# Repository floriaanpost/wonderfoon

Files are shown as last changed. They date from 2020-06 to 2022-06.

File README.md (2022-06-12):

<meta name="google-site-verification" content="D2DzTi8eTN-HyuHSnyPzxfvAiq60_1QDBox8yPDGH7g" />

# V3 is klaar!
Omdat ik zelf ook weer plezier kreeg in het project heb ik v3 gemaakt. Helaas (nog) geen DTMF, maar wel betere stabiliteit (minder vaak/nooit fouten met pulsen tellen) en makkelijker om de firmware te updaten (ISCP port). Ook zit er een LED op het board voor debugging (of om te laten zien dat hij aan staat).

Ik hoop dat het met deze versie gemakkelijker en leuker wordt voor mensen om te experimenteren met de code en het precies zo te maken als je zelf wil.

Heb je nog een oude versie, dan kun je wel de firmware gebruiken van v3 (alleen in wonderfoon.ino moet je OLD_PIN_CONFIG uncommenten), of anders kun je alles van v2 nog terugvinden in de v2 branch.

Verder valt het mij op dat mensen het lastig vinden om de Attiny te programmeren. Mocht dit je tegenhouden dan kan ik eventueel ook voorgeprogrammeerde chips opsturen, en vaak heb ik ook nog wel andere onderdelen liggen, en als je heel graag een wonderfoon wil, maar je kunt niet solderen, dan wil ik er misschien zelfs wel een voor je in elkaar solderen. Vraag even naar de mogelijkheden op de mail :)

# Wonderfoon mini
De Wonderfoon is een ouderwetse draaischijftelefoon waar je muziek te horen krijgt door de hoorn als je een nummer draait. Het is oorspronkelijk bedacht als "speelgoed" voor (demente) ouderen door Leo Willems. De ouderwetse telefoon uit hun jonge jaren, gecombineerd met muziek uit dezelfde tijd is vaak en leuke ervaring voor ouderen. Het oorspronkelijke idee is gemaakt met een Raspberry Pi (een soort kleine computer). Voor het oorspronkelijke plan moet de telefoon (onherstelbaar) gesloopt worden. Met inspiratie van [een project van Jan Derogee (TeleJukebox)](https://github.com/JanDerogee/TeleJukebox) heb ik een nieuw type Wonderfoon ontworpen. Hierbij hoeft de telefoon niet gesloopt te worden en kun je de stekker van de telefoon gemakkelijk in een doosje stoppen dat zich gedraagt als de telefooncentrale. Ook is de Raspberry Pi vervangen door een kleine mp3 speler (DFPlayer Mini) en een microcontroller (ATTiny85).

Ik krijg vaak soortgelijke vragen door mensen die de wonderfoon aan het bouwen zijn, onderaan deze pagina staat een FAQ sectie, lees die graag eerst voor je een vraag aan mij stuurt. Die beantwoord ik graag, maar ik houd ook erg van mijn weekend :)

# Foto's
De complete wonderfoon is in een klein doosje gestopt wat een standaard doosje is dat gemaakt wordt door Kopp en Q-link. Het printpaatje is zo ontworpen dat het precies past.

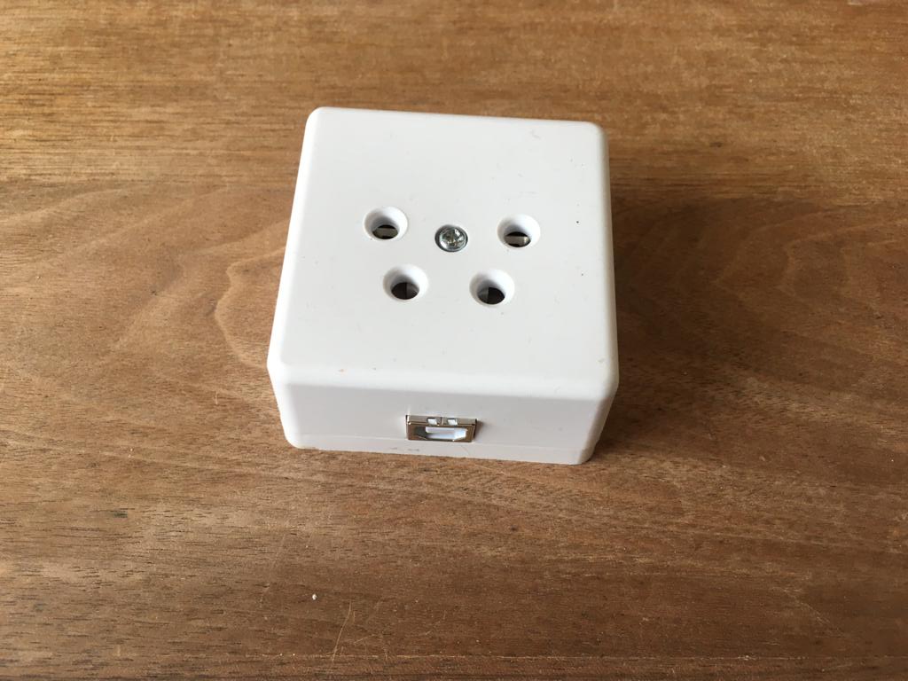
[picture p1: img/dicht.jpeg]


Als je het doosje openschroeft zie je het volgende:

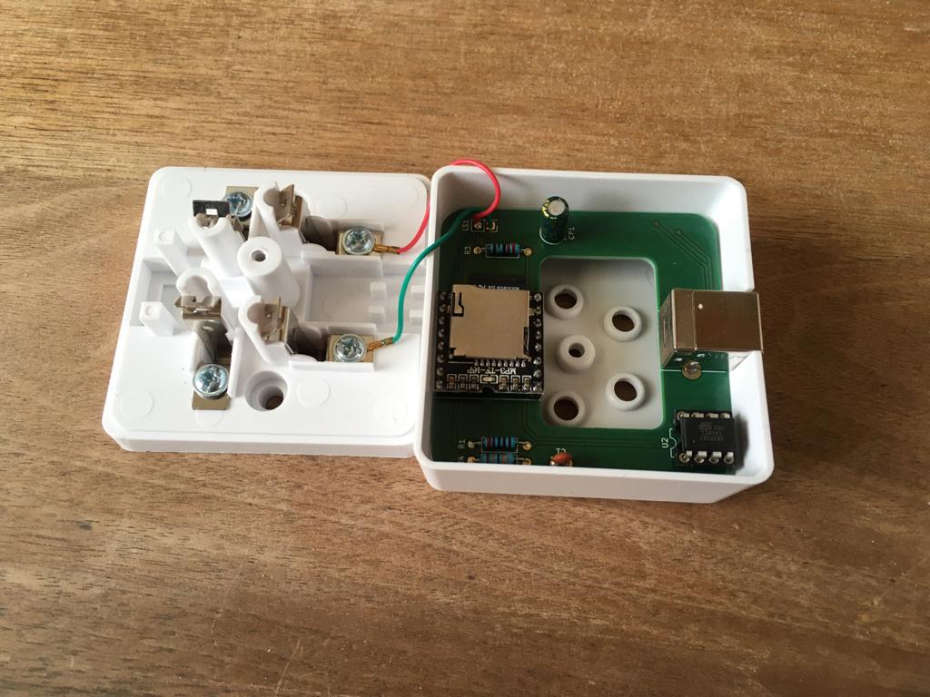
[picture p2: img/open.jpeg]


Er is een speciaal printplaatje ontworpen die precies in het doosje past.

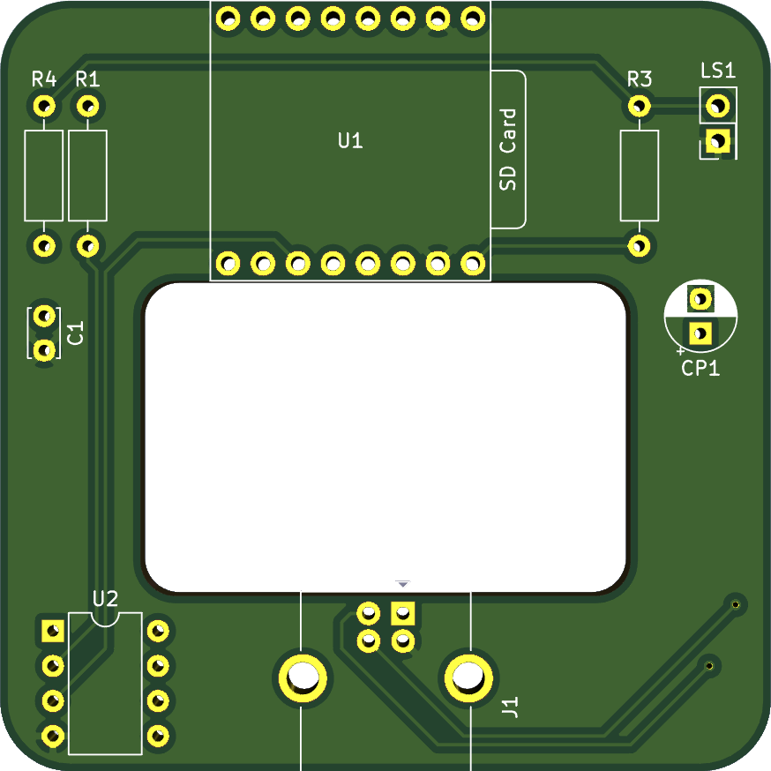
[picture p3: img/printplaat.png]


# Ik wil er een bouwen
In het bestand Bouwhandleiding Wonderfoon staat een handleiding van hoe je er een kunt solderen en programmeren. Met de gerberfiles kun je een printplaat bestellen. Let er goed op bij het bestellen dat je controleert of het midden ook echt een gat wordt voor je de bestelling plaatst. Ik heb ook nog behoorlijk wat printplaatjes liggen, dus je kunt ze ook bij mij bestellen.

# Componentenlijst
Ik kreeg de vraag waar je de componenten kunt kopen. Hieronder een voorbeeld. Dit is zonder enige twijfel niet de goedkoopste optie, maar het kan je in ieder geval helpen met de juiste componenten vinden:

- Attiny85: https://opencircuit.nl/Product/ATtiny85-DIP8
- DFPlayer mini: https://opencircuit.nl/Product/DFPlayer-Een-mini-mp3-speler-voor-Arduino
- Header pins (ICSP): https://opencircuit.nl/Product/Male-header-2x40-2.54mm-zwart
- USB type B connector: https://www.conrad.nl/p/econ-connect-usbbu1bn-usb-connector-bus-inbouw-horizontaal-wit-1-stuks-1883654
- 10 uF elco: https://opencircuit.nl/Product/10uF-35V-Condensator-elektrolytisch
- 1 uF elco: https://opencircuit.nl/Product/1uF-450V-Condensator-elektrolytisch
- LED (optioneel): https://opencircuit.nl/Product/Rood-5mm-diffuse-LED-10-stuks
- 10 kOhm weerstand: https://opencircuit.nl/Product/10K%CE%A9-Metaalfilm-weerstand-1-4W-10-stuks
- 220 Ohm weerstand: https://opencircuit.nl/Product/220%CE%A9-Metaalfilm-weerstand-1-4W-10-stuks
- 2.7 kOhm (dit is 2kOhm, maar dat is ook wel prima): https://opencircuit.nl/Product/2K%CE%A9-Metaalfilm-weerstand-1-4W-10-stuks
- Telefooncontactdoos https://www.gamma.nl/assortiment/q-link-telefoon-contactdoos-opbouw-modulair-4-polig-wit/p/B547149

# De liedjes nummeren is veel moeite...
Hier heeft Daan een python scriptje voor gemaakt dat je kunt gebruiken:
https://github.com/daanv98/mp3nu

Je kunt ook file renamer gebruiken:
http://www.sherrodcomputers.com/products_filerenamer.cfm

# FAQ
Ik krijg vaak soortgelijke vragen die ik hieronder zal beantwoorden:

#### Hoe moet ik de bestanden op de SD kaart zetten (lees dit sowieso even door, dit zorgt voor het meest problemen)
De DFplayer mini is een handig en goedkoop stukje hardware, maar heeft een paar vreemde eigenschappen, waar je rekening mee moet houden als je bestanden op de SD kaart zet. Met de onderstaande stappen gaat het (bij mij althans) altijd goed:

- Formatteer de SD kaart (FAT)
- Zet eerst de 01/ map erop (https://github.com/floriaanpost/wonderfoon/tree/master/muziek). Dit mapje bevat de kiestoon die je hoort als je de hoorn van de haak neemt en de verbinding verbroken toon en nog wat zaken. Het is van cruciaal belang dat je dit eerst doet voor dat je iets met een MP3 map doet. Dit komt omdat de DFPlayer mini de nummering doet op basis van de volgorde waarop de liedjes op de SD kaart zijn gezet, dus die moeten als aller eerst op de SD kaart worden gezet.
- Maak hierna een mapje genaamd MP3 in de hoofdmap. Zet hierin liedjes op volgorde genummerd, startend met precies 4 cijfers. Alleen de eerste vier cijfers maken uit, daarna kun je alles schrijven wat je wil. Dit nummeren is veel werk, dus daarvoor kun je eventueel het Python scriptje van Daan gebruiken (zie hierboven), of zelf een bash-kunstwerktje maken, of gewoon handmatig te werk gaan. Let op dat er geen gaten zitten in de nummering! Zie als voorbeeld: https://github.com/floriaanpost/wonderfoon/tree/master/muziek/MP3
- Laat hierna de 01 map voor altijd met rust, je kunt wel dingen aanpassen in de MP3 map, maar let op dat er geen verborgen bestanden ontstaan op de SD kaart, die ziet de DFPlayer mini niet als verborgen bestanden, en dat kan zorgen voor vreemde problemen.

Als je een mac hebt (ik ben zelf zo'n persoon) heb je een beetje een probleem. Mac is heel gretig in het produceren van verborgen bestanden en hele trash mappen op sd kaarten. Het is mij maar zelden gelukt om het daar goed te doen. Ik pak nu altijd mijn Linux laptop, wat verreweg het beste gaat op dit gebied. Windows zorgt ook voor weinig problemen.

#### Ik heb de bestanden precies zoals hierboven op mijn SD kaart gezet, en toch werkt het niet.
Ik heb iemand gehad die SD kaartjes had gekocht die ook ik niet aan de praat heb gekregen. We hebben nog steeds geen idee wat het probleem was. Ik heb vaak de allergoedkoopste Kingston SD kaart gebruikt die ik kon vinden en daar nog nooit problemen mee gehad. Geen idee dus wat dit precies kan zijn, maar een andere SD kaart proberen is geen slecht idee.

#### Ik denk dat mijn ATtiny85 niet goed is geprogrammeerd
Als de led op enig moment knippert, betekent dat hoogstwaarschijnlijk dat de ATtiny85 goed is geprogrammeerd, aangezien die de LED aanstuurt, als de LED dus knippert, zoek dan naar een andere oorzaak dan de ATtiny85. Doet de LED helemaal niets, dan is er een goede kans dat de ATtiny85 inderdaad niet goed is geprogrammeerd. 

#### De LED blijft knipperen, en de wonderfoon werkt niet
Zo lang de led knippert is de ATtiny85 bezig met verbinding maken met de kleine MP3 speler, de DFPLayer mini. Dit gaat zelden meteen goed zodra je hem in het stopcontact steekt, de DFPlayer heeft wat meer tijd nodig om op te starten dan de ATtiny85. Als het knipperen echter niet stopt, dan gaat er iets mis. Dit kan betekenen dat er geen SD kaart in de DFPlayer zit (maar ik ga ervan uit dat jullie dat niet vergeten), of dat er iets is waardoor de bestanden op de SD kaart niet goed gelezen kunnen worden, zie het eerste punt over hoe je bestanden op de SD kaart moet zetten, en het tweede punt over sommige SD kaarten die niet werken.

#### Ik hoor bijvoorbeeld de "verkeerd verbonden" toon als ik de hoorn opneem in plaats van de kiestoon, of meteen een liedje
Zet de liedjes juist op de SD kaart, zoals beschreven in het eerste punt. Als je een mac hebt, probeer een windows/linux computer te vinden en probeer het daarmee, of zoek uit hoe het wel lukt op een mac en vertel het mij ;)

#### Ik wil de ATtiny85 programmeren met een Arduino, maar het lukt me niet
Een USBasp is veel makkelijker om te programmeren, en heel goedkoop, maar als je het toch met een arduino wil doen kun je deze handleiding volgen:
https://create.arduino.cc/projecthub/arjun/programming-attiny85-with-arduino-uno-afb829
Er is alleen een ding dat hier niet vermeld staat en dat is dat wanneer je de "ArduinoISP" sketch op de arduino zet je regel 81 moet uncommenten (// #define USE_OLD_STYLE_WIRING). Verder is gebruik ik een kloksnelheid van 1MHz voor de attiny (hoewel hoger ook zou moeten werken).

#### De sketch compileert niet bij het programmeren. 
Je moet de attiny eerst toevoegen aan de arduino IDE.
Volg de instructies van deze repository: https://github.com/damellis/attiny

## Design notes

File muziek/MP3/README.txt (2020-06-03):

Als voorbeeld staan er twee "nummers" in deze map. In het echt moeten dat natuurlijk mp3 bestanden zijn. Wel moeten ze op precies deze manier genummerd worden. Vier getallen vanaf 0001, daarna een spatie en dan mag er alles staan wat je zelf maar wil. Ook mogen er geen getallen worden overgeslagen want dan wordt de lijn verbroken als je wel dat nummer probeert te bellen.

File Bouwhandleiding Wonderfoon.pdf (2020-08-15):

## Handleiding Wonderfoon

Floriaan Post

February 2020

## Inleiding

De Wonderfoon is een ouderwetse draaischijftelefoon waar je muziek te horen krijgt door de hoorn als je een nummer draait. Het is oorspronkelijk bedacht als "speelgoed" voor (demente) ouderen door Leo Willems. De ouderwetse telefoon uit hun jonge jaren, gecombineerd met muziek uit dezelfde tijd is vaak en leuke ervaring voor ouderen. Het oorspronkelijke idee is gemaakt met een Raspberry Pi (een soort kleine computer). Voor het oorspronkelijke plan moet de telefoon (onherstelbaar) gesloopt worden. Met inspiratie van een project van Jan Derogee (https://github.com/JanDerogee/TeleJukebox) heb ik een nieuw type Wonderfoon ontworpen. Hierbij hoeft de telefoon niet gesloopt te worden en kun je de stekker van de telefoon gemakkelijk in een doosje stoppen dat zich gedraagt als de telefooncentrale. Ook is de Raspberry Pi vervangen door een kleine mp3 speler (DFPlayer Mini) en een microcontroller (ATTiny85). De onderstaande bouwhandleiding is bedoelt voor die versie van de Wonderfoon.

## Componenten

De volgende electronische componenten zijn nodig voor het maken van de wonderfoon:

Code op printplaat | Component | Uitleg
U1 | DFPlayer mini | Mini mp3 speler
U2 | ATTiny85 | Microcontroller
J1 | USB Type B socket
J2 | ICSP port | 2 x 3 header pins
CP1 | 10 uF | Elektrolytische condensator
CP2 | 1 uF | Elektrolytische condensator
R1 | 2.7 kΩ | Weerstand
R2 | 220 Ω | Weerstand
R3 | 10 kΩ | Weerstand
R4 | 220 Ω | Weerstand (Optioneel)
D1 | LED | Optionele LED voor debugging
SD Card | | Micro SD kaart

De printplaat waarop de componenten gesoldeerd moeten worden inclusief nummering staat in figuur 1a.

Het laatste component dat uitleg verdient is het doosje waar het geheel in moet. Dit is een doosje dat eigenlijk is bedoelt om van een ouderwetse PPT stekker (de stekker die aan de draaischijftelefoon zit) naar je modem te kunnen gaan. Dit doosje is erg geschikt voor de Wonderfoon. Er zijn twee opties hiervoor, namelijk de versie van Q-Link (verkrijgbaar bij onder andere de Gamma) en die van Kopp (verkrijgbaar bij onder andere de Praxis). Deze zijn min of meer identiek en beiden te gebruiken, maar ik heb zelf een voorkeur voor de versie van Q-Link want die is iets mooier afgewerkt. De kosten zijn (min of meer) hetzelfde. In figuur 1b staat een voorbeeld van zo’n telefooncontactdoos.

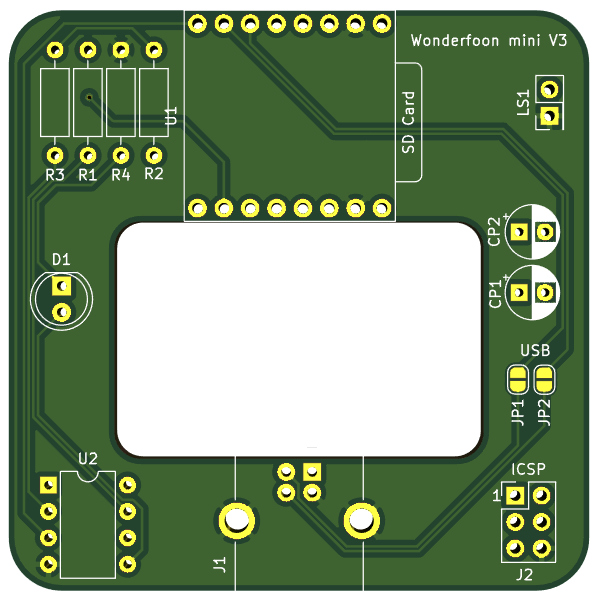
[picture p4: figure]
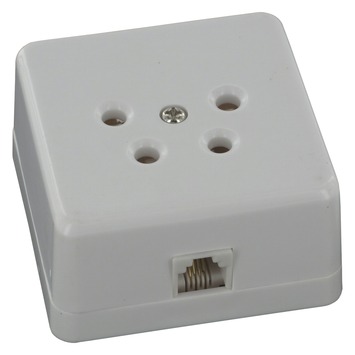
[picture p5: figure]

(a) De printplaat met de nummering van de componenten. | (b) Q-Link telefooncontactdoos

Figure 1: Speciale onderdelen

## Montage

Zorg dat de soldeerbout warm is. Bij het solderen is het belangrijk dat je beide delen die je vast wil solderen verwarmt waarna je een beetje soldeertin toevoegt en alles aan elkaar smelt. Als het er goed uitziet kun je de soldeerbout weer weghalen. Hieronder een aantal algemene tips om het solderen wat makkelijker te maken:

1. Begin met de kleinste componenten met korte pootjes. Deze vallen er weer uit als je dit pas later doet, wat het moeilijk maakt ze te monteren.
2. Je hebt maar een klein beetje soldeertin nodig per pootje dat je vastmaakt. Teveel soldeertin maakt de verbinding minder sterk en je verhoogt het risico dat er een elektrische verbinding ontstaat met een ander pootje.
3. Componenten met lange pootjes zoals weerstanden en condensatoren kun je ombuigen nadat je ze door de juiste gaatjes hebt gehaald. Hierdoor blijven ze hangen en kun je makkelijker solderen.

Gezien regel 1 kun je in dit geval het beste beginnen met het IC-voetje. Hierna maakt het allemaal wat minder uit maar ik zou adviseren om daarna de DFPlayer mini te doen. Hierna de weerstanden en de condensator. Als laatste de Elco’s (elektrolytische condensatoren) en de USB port.

Als laatste moet je de connectoren voor de telefoonlijn vast solderen. Hiervoor moet je het doosje van figuur 1b openschroeven. Je treft dan iets soortgelijks aan als in figuur 2a. Je moet alle contactpunten losschroeven en dan kan je het het geheel (het doet mij altijd denken aan een soort octopus) eruit halen. Je moet nu twee van de stroomdraden afknippen omdat je die nog nodig hebt. Ik kies altijd de rode en de groene, zie figuur 2b omdat je als het klaar is de draden ook weer aan die contactpunten vastmaakt. De rest van de "octopus" heb je niet nodig en kun je weggooien. Strip de uiteinden van de kabeltjes en soldeer ze vast bij LS1. In welk gaatje van LS1 je welke kleur draad vastmaakt maakt niet uit. Dit komt doordat de telefoon analoog is en het dus niet uitmaakt hoe om de spanning wordt aangesloten. Wat wel uitmaakt is waar je de draden vastzet in het doosje. De draden moeten naar de brede kant van de PPT stekker, zie hiervoor figuur 3.

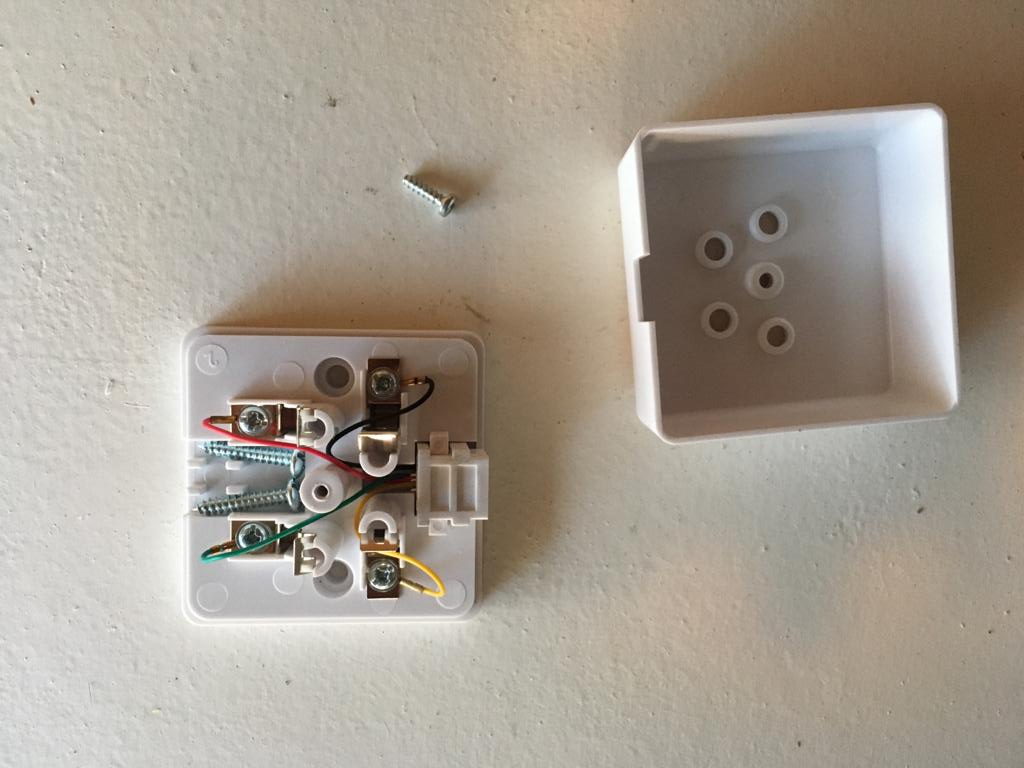
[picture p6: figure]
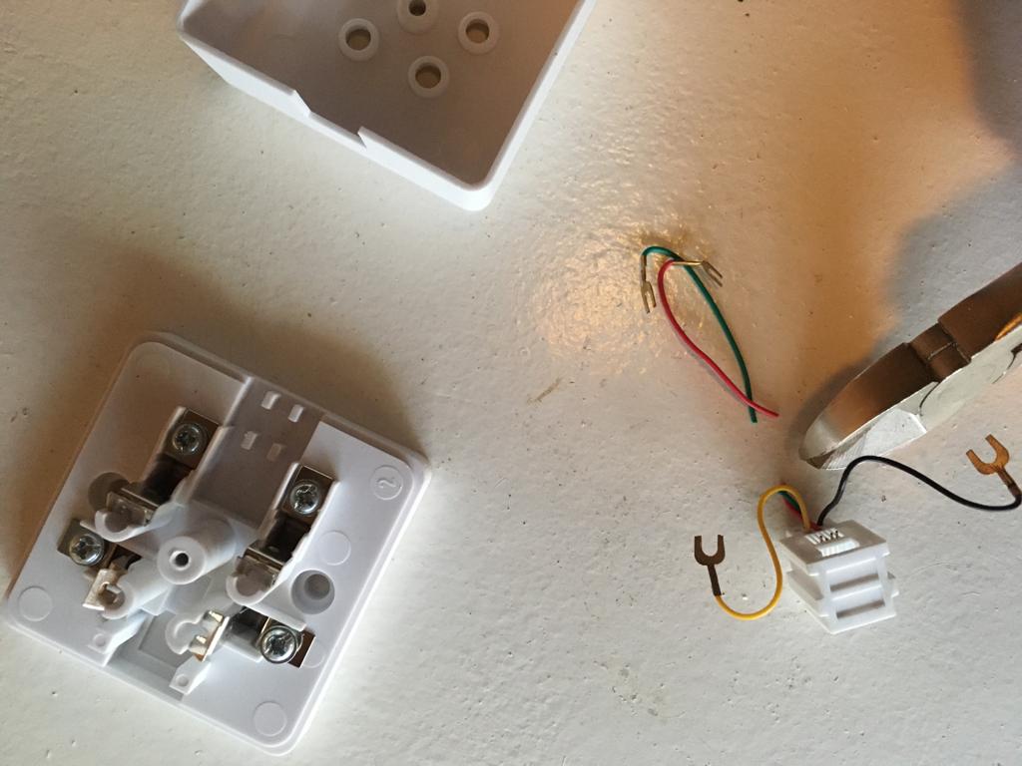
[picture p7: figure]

(a) De geopende telefooncontactdoos. | (b) Losknippen van de rode en groene draad.

Figure 2: Telefooncontactdoos demonteren


Figure 3: bevestigen draden aan het doosje.

## Microcontroller programmeren

Als alles in elkaar is gesoldeerd, is het tijd om de microcontroller (Attiny85) te programmeren. Er komt dan een klein programma op de microcontroller dat kan detecteren of de telefoon van de haak wordt gehaald en welk nummer er gedraaid wordt. Ook stuurt de microcontroller de mp3 speler aan als er gedetecteerd is welk nummer er gespeeld moet worden. Het programma is geschreven in Arduino C++. Je hebt dus het programma Arduino nodig. Dit programma is gratis te downloaden voor Windows, Mac en Linux op hun website. (https://www.arduino.cc/en/Main/Software)

ATTiny85 toevoegen in de Arduino IDE

Als je dit eenmaal hebt geinstalleerd moet je de ATTiny85 toevoegen in de Arduino IDE (je kunt niet standaard de ATTiny85 programmaren). Hieronder de korte handleiding om hem toe te voegen. Dit hoef je maar een keer te doen en kun je dus overslaan als je dit al eens gedaan hebt.

1. Klik op File → Preferences.
2. Voeg bij "Additional boards manager" de volgende url toe:

https://raw.githubusercontent.com/damellis/attiny/ide-1.6.x-boards-manager/package_damellis_attiny_index.json

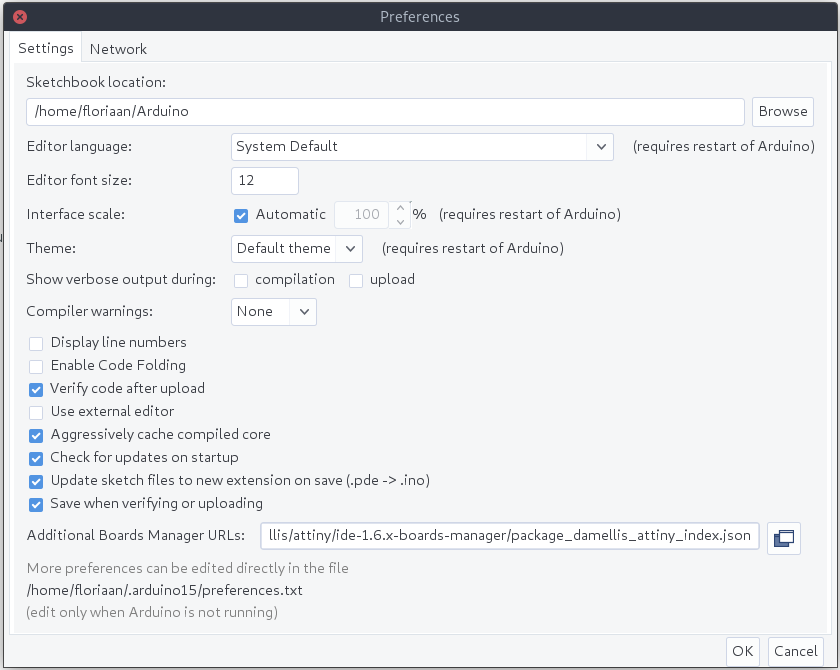
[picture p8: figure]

3. Klik op OK.
4. Start de Arduino IDE opnieuw op.
5. Ga naar Tools → Board → Board manager.
6. Zoek in het zoekveld naar attiny en installeer de library gemaakt door David A. Mellis.
7. Alles is nu klaar om de code op de Attiny te zetten.

Arduino instellen voor het programmeren

Nu moet je alles goed instellen om de ATTiny85 te programmeren. Dit is handig om elke keer als je er 1 of meerdere gaat programmeren te checken voor de zekerheid.

1. Klik op Tools → Board: "ATtiny25/45/85". Mocht deze er niet tussen staan en je hebt wel de ATTiny toegevoegd, probeer dan eens Arduino IDE af te sluiten en opnieuw op te starten.
2. Klik op Tools → Processor: "ATtiny85".
3. Klik op Tools → Clock: "Internal 1 MHz".
4. Klik op Tools → Programmer: "Arduino as ISP".

Microchip programmeren

Als alles nog goed staat van een eerdere keer programmeren kun je meteen bij deze stap beginnen. Ik ga er vanuit
dat je een ISCP programmer hebt (zoals de USBasp).

Als je dit niet hebt, maar wel een Arduino, dan kun je ook deze handleiding gebruiken: https://www.instructables.com/id/How-to-Program-an-Attiny85-From-an-Arduino-Uno/ (https://www.instructables.com/id/How-to-Program-an-Attiny85-From-an-Arduino-Uno/) Je moet dan even de mapping van de ICSP poort opzoeken en die
juist aansluiten.
1. Sluit de usbASP aan op je computer en op de wonderfoon. Let erop dat pin 1 MISO is.

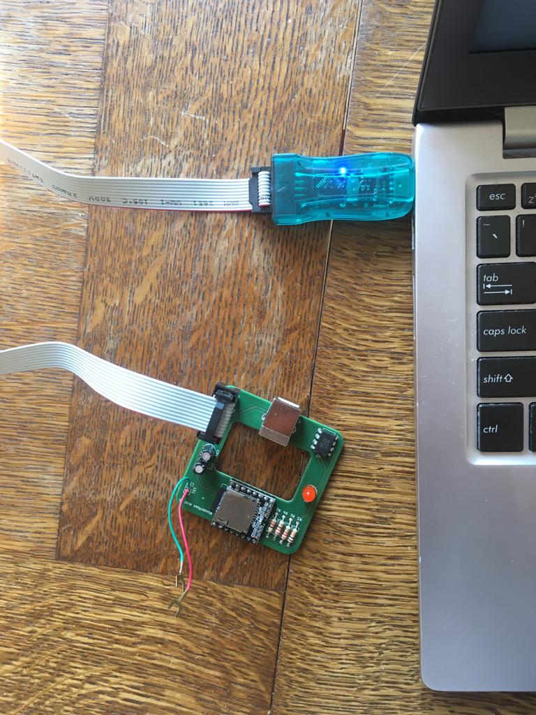
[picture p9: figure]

2. Open de sketch wonderfoon.ini.
3. Klik op Tools → Programmer → USBasp (of als je een andere programmer hebt, selecteer die dan).
4. Klik op Tools → Burn bootloader (dit is nodig om de kloksnelheid juist te zetten en dergelijke)
5. Klik op het pijltje naar rechts bovenaan om het programma te uploaden.

Als dit allemaal gelukt is is de microcontroller geprogrammeerd en werkt het hopelijk!

## Liedjes op de SD kaart zetten

Je moet alleen nog de liedjes op de SD kaart zetten en dan is het klaar. Kopieer de map MP3/ en de map 01/ naar de SD kaart. In de map MP3/ zitten de echte liedjes en in de map 01/ zitten dingen zoals de kiestoon en dergelijke. Je moet nooit iets aan deze map veranderen tenzij je weet wat je aan het doen bent. In de MP3 map zitten liedjes. Deze liedjes moeten altijd het nummer van het liedje in de titel hebben en altijd precies 4 getallen lang zijn. Als voorbeeld:

0001 Vader Abraham - Daar In Dat Kleine Café Aan De Haven
0002 Benny Neyman - Een Vrijgezel Gaat Pas Slapen
0003 Het Dorp - Wim Sonneveld

Je kunt deze liedjes ook veranderen door het kastje via een USB kabel aan te sluiten op je computer. Dit gaat echter langzamer dan direct op het SD kaartje zetten.

## Alles samenvoegen

Het is nu tijd om het SD kaartje in de DFPlayer mini te stoppen, het groene en rode kabeltje weer vast te maken in het doosje (zie figuur 2a voor waar de kabeltjes moeten, links en recht maken niet uit) en tot slot het doosje dicht te schroeven op zo’n manier dat de USB connector door het vierkante gat steekt in het doosje. Je kunt nu het doosje via een USB kabel en een adapter aansluiten en een telefoon in het doosje stoppen en hopen dat je alles goed hebt gedaan!

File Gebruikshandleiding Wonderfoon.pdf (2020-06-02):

## Handleiding Wonderfoon

Floriaan Post

February 2020

## Inleiding

De Wonderfoon is een ouderwetse draaischijftelefoon waar je muziek te horen krijgt door de hoorn als je een nummer draait. Het is oorspronkelijk bedacht als "speelgoed" voor (demente) ouderen door Leo Willems. De ouderwetse telefoon uit hun jonge jaren, gecombineerd met muziek uit dezelfde tijd is vaak en leuke ervaring voor ouderen. Het oorspronkelijke idee is gemaakt met een Raspberry Pi (een soort kleine computer). Voor het oorspronkelijke plan moet de telefoon (onherstelbaar) gesloopt worden. Met inspiratie van een project van Jan Derogee (https://github.com/JanDerogee/TeleJukebox) heb ik een nieuw type Wonderfoon ontworpen. Hierbij hoeft de telefoon niet gesloopt te worden en kun je de stekker van de telefoon gemakkelijk in een doosje stoppen dat zich gedraagt als de telefooncentrale. Ook is de Raspberry Pi vervangen door een kleine mp3 speler (DFPlayer Mini) en een microcontroller (ATTiny85). De onderstaande gebruikshandleiding is bedoelt voor die versie van de Wonderfoon.

## Gebruik

De Wonderfoon heeft twee modi. De eerste modus is de gebruiksmodus. In deze modus wordt de Wonderfoon gebruikt zoals hij bedoelt is en kun je nummers draaien op de telefoon en hoor het het corresponderende liedje. In de tweede modus kun je liedjes op de Wonderfoon zetten of de bestaande nummers wijzigen. Je hebt behalve een Wonderfoon-doosje ook nog meer dingen nodig om aan de slag te kunnen. In figuur 1 staan ze allemaal.

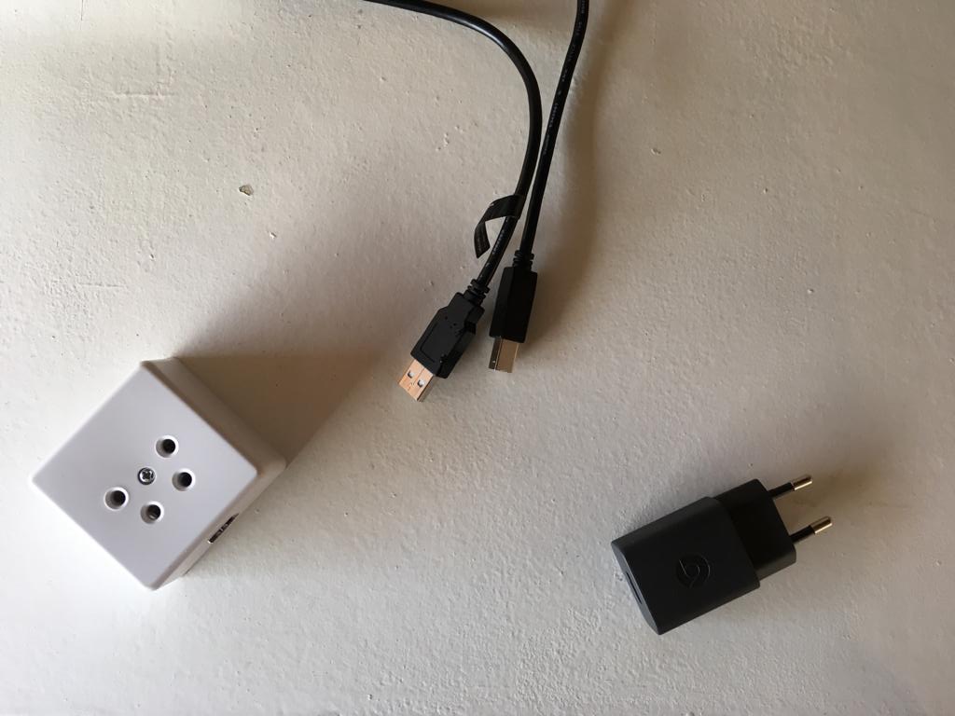
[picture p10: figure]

Figure 1: Van links naar rechts; de Wonderfoon, een USB kabel (type A naar type B) en een adapter met USB uitgang

Gebruiksmodus

De Wonderfoon wordt dan met een USB type B kabel aangesloten op een adapter. Deze adapter stop je in het stopcontact. De telefoon stop je in het vier gaten van de PPT-stekker. Je kunt een nummer draaien en je hoort dan het corresponderende liedje. Als je een nummer draait dat hoger is dan het aantal liedjes op de Wonderfoon begint hij weer van voren af aan. Als er dus 80 liedjes op de Wonderfoon staan en je draait op de telefoon 8-1, dan wordt het eerste nummer weer gedraaid. Verder zijn er nog een paar speciale nummers. Dit zijn; 112, 0611 en 911. Als je een van deze nummers draait krijg je een bericht te horen dat de telefoon niet is verbonden en je een andere telefoon moet zoeken of om hulp moet vragen. Je kunt de audiotrack eventueel wijzigen in de tweede modus van de telefoon.

Configuratiemodus

Er zijn twee manieren om liedjes op de Wonderfoon te zetten. Je kunt het USB kabeltje dat normaal in de adapter zit op je computer aansluiten of je kunt de Wonderfoon openschroeven en het micro SD kaartje eruit halen. Het tweede heeft als voordeel dat het kopiëren van liedjes veel(!) sneller gaat. Als je dus maar een paar kleine wijzigingen wil doen zou ik de Wonderfoon op je computer aansluiten en als je alle liedjes wil veranderen (of in ieder geval een heel groot deel), dan kun je misschien beter even het doosje openmaken en het SD kaartje eruit halen. Je hebt dan wel een lezer nodig voor in je computer.

Of je nou de Wonderfoon direct op je computer hebt aangesloten of via het SD kaartje, de volgende stappen zijn hetzelfde. Je zult op je computer de Wonderfoon zien als een USB stick. Als je die opent zie je twee mapjes zoals in figuur 2. Je ziet de mapjes MP3/ en 01/. Het mapje 01/ hoef je in principe nooit iets aan te veranderen. In dit mapje staan de tracks voor de kiestoon en de "verbinding-verbroken-track".

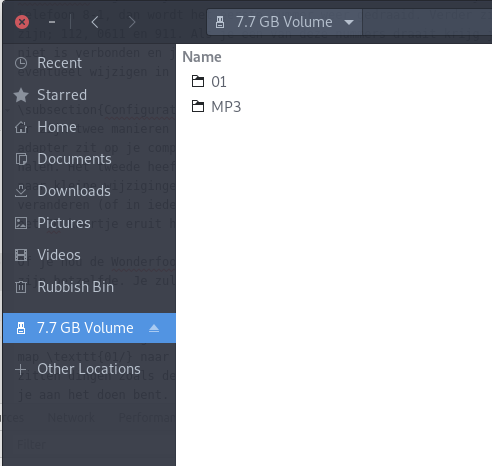
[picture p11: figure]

Figure 2: Mapjes op de wonderfoon

Als je liedjes wil wijzigen moet je het mapje MP3 openen. Hierin zie je de liedjes netjes genummerd staan. Deze nummering is heel belangrijk. Elke nummer voor de titel van het liedje moet uit precies 4 cijfers bestaan. Wat hierna komt maakt verder niet uit. Als voorbeeld:

0001 Vader Abraham - Daar In Dat Kleine Café Aan De Haven
0002 Benny Neyman - Een Vrijgezel Gaat Pas Slapen
0003 Het Dorp - Wim Sonneveld

Ook mag er geen nummer overgeslagen worden of dubbel voorkomen. De Wonderfoon blijft dan wel werken, maar er gebeuren dan een aantal onverwachte dingen.

Tot slot kun je ook de noodgevallen-track veranderen. Dit kan door het mapje 01/ te openen en het bestand "004_emergency.mp3" te overschrijven met een ander bestand. Deze moet exact hetzelfde heten.

Belangrijk voor Mac en Linux

Als je op Mac of Linux zit moet je verder nog ergens op letten. Als je dan namelijk een liedje weggooit wordt dit nummer niet echt weggegooid. Dit is een probleem omdat het dan voor het mp3 spelertje in de Wonderfoon lijkt alsof het oude nummer nog bestaat. Het wordt namelijk in een soort prullenbak op de SD kaart gezet.

Op Mac kun je dit voorkomen door de volgende app te gebruiken: http://www.zeroonetwenty.com/blueharvest/. Ik ben zelf geen Mac gebruiker dus weet verder niet hoe je het gebruikt.

Voor Linux geldt hetzelfde probleem. Als je Nautilus gebruikt als file browser, dus je in een mapje CTR-H doen om de verborgen bestanden weer te geven. Als je dan alle verborgen mapjes nogmaals weggooit is het probleem opgelost.

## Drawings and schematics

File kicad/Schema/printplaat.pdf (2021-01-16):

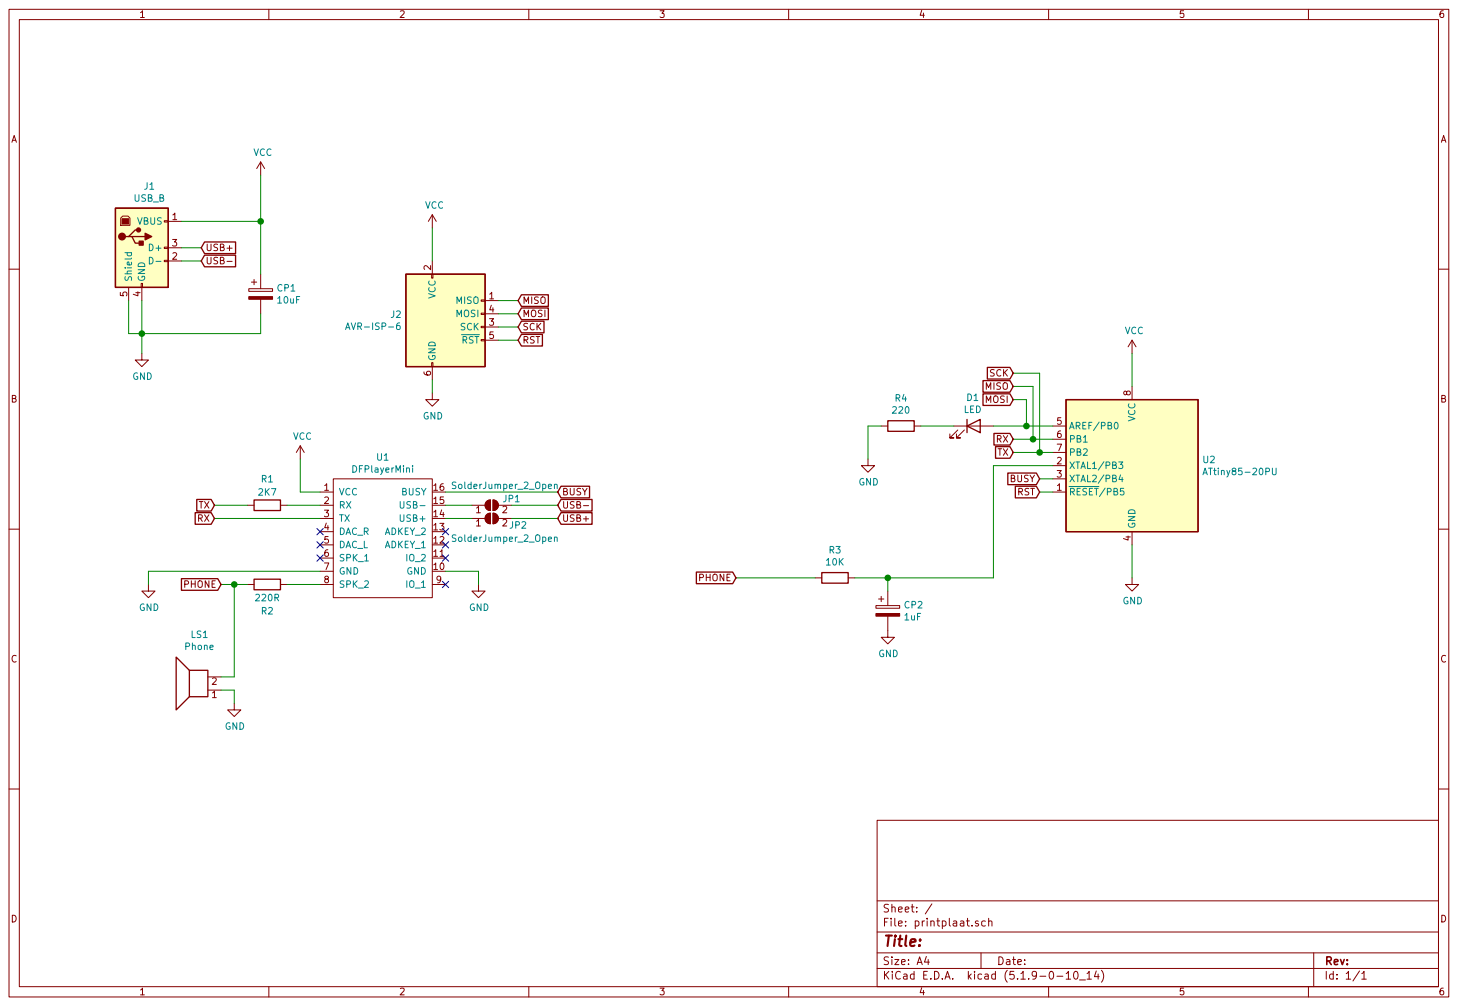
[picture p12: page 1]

2 SCK 3 MOSI 4 RST 5 GND

File: printplaat.sch Sheet: /
Id: 1/1 Title:

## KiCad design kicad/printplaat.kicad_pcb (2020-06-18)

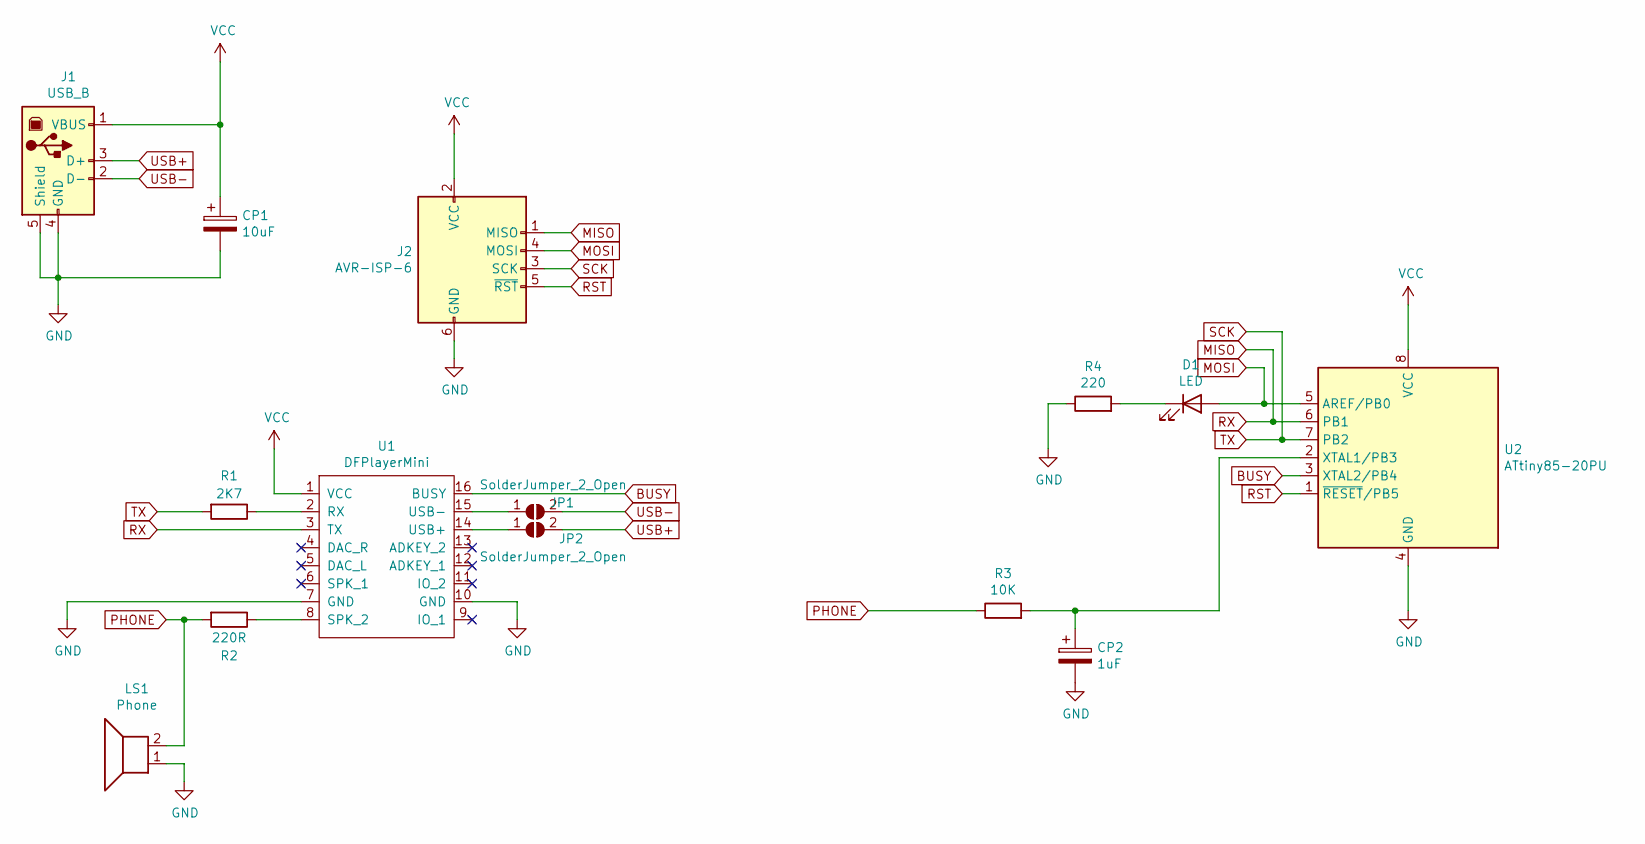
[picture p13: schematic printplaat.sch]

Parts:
CP1: 10uF; CP_Radial_D5.0mm_P2.50mm
CP2: 1uF; CP_Radial_D5.0mm_P2.50mm
D1: LED; LED_D5.0mm
J1: USB_B; USB_B_OST_USB-B1HSxx_Horizontal
J2: AVR-ISP-6; PinHeader_2x03_P2.54mm_Vertical
JP1, JP2: SolderJumper_2_Open; SolderJumper-2_P1.3mm_Open_RoundedPad1.0x1.5mm
LS1: Phone; PinHeader_2x01_P2.54mm_Vertical
R1: 2K7; R_Axial_DIN0207_L6.3mm_D2.5mm_P10.16mm_Horizontal
R2: 220R; R_Axial_DIN0207_L6.3mm_D2.5mm_P10.16mm_Horizontal
R3: 10K; R_Axial_DIN0207_L6.3mm_D2.5mm_P10.16mm_Horizontal
R4: 220; R_Axial_DIN0207_L6.3mm_D2.5mm_P10.16mm_Horizontal
U1: DFPlayerMini; DFPlayer_Mini
U2: ATtiny85-20PU; DIP-8_W7.62mm

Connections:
BUSY: U1.16 (BUSY), U2.3 (XTAL2/PB4)
GND: CP1.2, CP2.2, J1.4 (GND), J1.5 (Shield), J2.6 (GND), LS1.1, R4.1, U1.7 (GND), U1.10 (GND), U2.4 (GND)
MISO: J2.1 (MISO), U1.3 (TX), U2.6 (PB1)
MOSI: D1.2 (A), J2.4 (MOSI), U2.5 (AREF/PB0)
unnamed: CP2.1, R3.2, U2.2 (XTAL1/PB3)
unnamed: D1.1 (K), R4.2
unnamed: JP1.1 (A), U1.15 (USB-)
unnamed: JP2.1 (A), U1.14 (USB+)
unnamed: R1.1, U1.2 (RX)
unnamed: R2.1, U1.8 (SPK_2)
PHONE: LS1.2, R2.2, R3.1
RST: J2.5 (~RST), U2.1 (~RESET~/PB5)
SCK: J2.3 (SCK), R1.2, U2.7 (PB2)
USB+: J1.3 (D+), JP2.2 (B)
USB-: J1.2 (D-), JP1.2 (B)
VCC: CP1.1, J1.1 (VBUS), J2.2 (VCC), U1.1 (VCC), U2.8 (VCC)

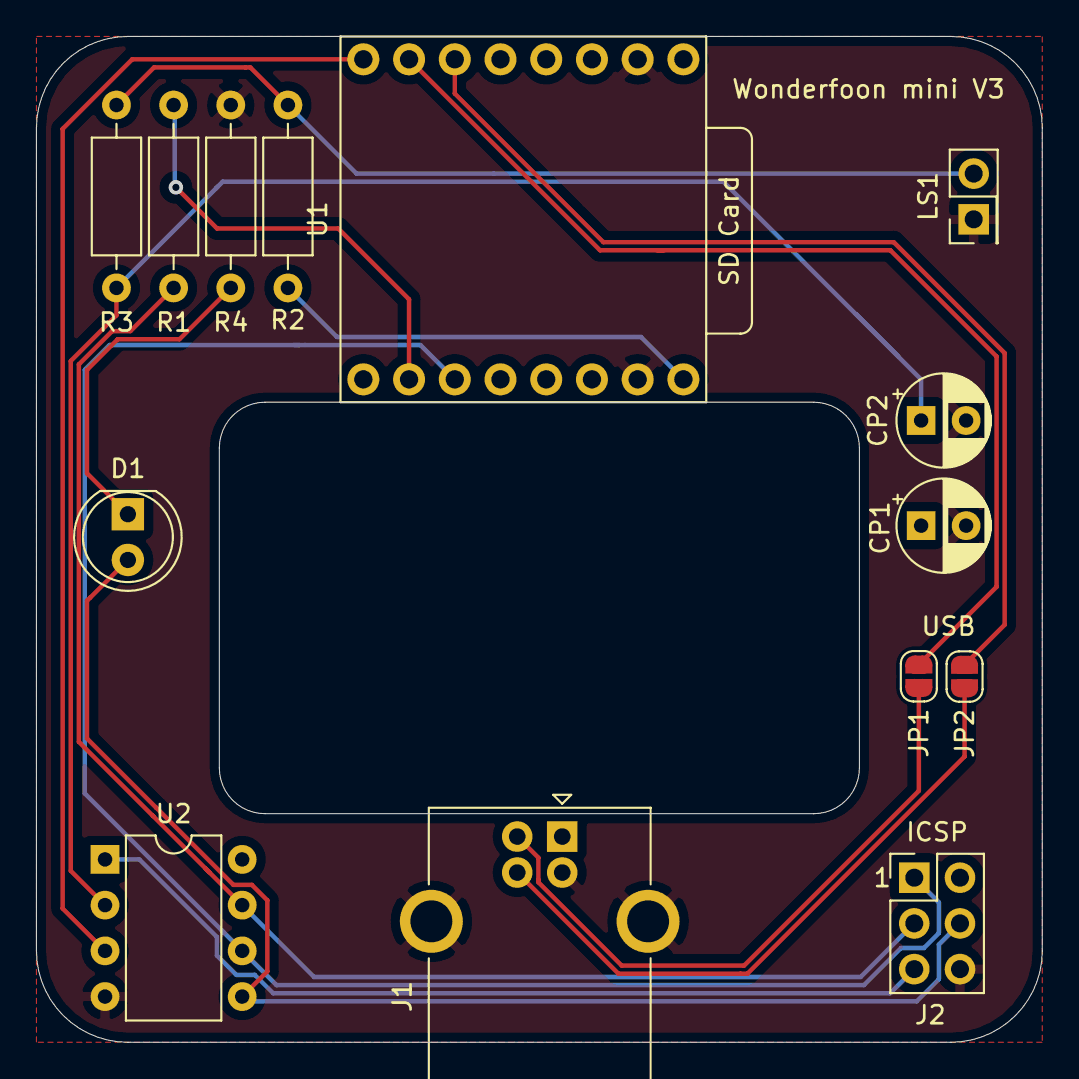
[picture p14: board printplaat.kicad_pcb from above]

Board: 2 copper layers, 55.9 x 55.9 mm, 14 parts (0 on the bottom side), 16 nets.

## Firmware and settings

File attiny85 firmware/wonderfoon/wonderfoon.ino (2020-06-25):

/* code written for ATTiny85
 * Tested only for internal oscillator at 1MHz
 * Arduino as ISP
 * by Floriaan Post
 */

#include "SoftwareSerial.h"
#include "DFRobotDFPlayerMini.h"
#include "Phone.h"

// uncomment this if you have an old version
// #define OLD_PIN_CONFIG

// debug on or off
#define DEBUG true

// pin config on attiny85
#define PIN_LED 0
#define PIN_PHONE A3
#define PIN_BUSY 4
#define TX 2
#define RX 1

#ifdef OLD_PIN_CONFIG
#define PIN_LED 0
#define PIN_PHONE A1
#define PIN_BUSY 1
#define TX 3
#define RX 4
#endif

// dial done when no new numbers detected after this timeout
#define LONG_TIMEOUT 2500

// service sound files (in 01/ folder)
#define DIAL_TONE 1
#define DISCONNECTED_TONE 2
#define WRONG_NUMBER_TONE 3
#define EMERGENCY_TRACK 4

// error codes (only used for debugging)
#define ERROR_DFPLAYER_INIT 1
#define ERROR_FILE_COUNT 2
#define ERROR_SERVICE_FILE_COUNT 3

int songCount;
int phoneState;
int playerState;
unsigned long timeOfLastInput = 0;
unsigned long lastPoll = 0;
String number = "";
bool isPlayingSong = false;
bool isWaitingForHook = false;


SoftwareSerial mp3Serial(RX, TX);
DFRobotDFPlayerMini mp3Player;
Phone phone(PIN_PHONE, DEBUG);

void(* resetFunc) (void) = 0; //declare reset function @ address 0

void blink() {
  digitalWrite(PIN_LED, HIGH);
  delay(300);
  digitalWrite(PIN_LED, LOW);
  delay(300);
}


void error(int code) {
  if (DEBUG) {  
    // blink error code and reset after!
    for (int i = 0; i < code; i++) {
      blink();
    }
    delay(1000);
  }
  resetFunc();
}

void numberCalled(String number) {
  isPlayingSong = true;
  
  if (number == "112" || number == "0611" || number == "911") {
    mp3Player.play(EMERGENCY_TRACK);
  } else {
    // loop if song is number > songCount (unsigned int is probably not long enough to store number, but that's not really a problem as long as the same number is called every time)
    unsigned int calledNumber = (number.toInt() - 1) % songCount + 1;
    if (calledNumber > 0) {
      mp3Player.playMp3Folder(calledNumber);
    } else {
      isPlayingSong = false;
      isWaitingForHook = true;
      mp3Player.loop(WRONG_NUMBER_TONE);
    }
  }
  // wait until song actually starts playing!
  delay(300);
}


void setup() {
  pinMode(PIN_LED, OUTPUT);
  pinMode(PIN_BUSY, INPUT);
  mp3Serial.begin(9600);
  
  // give the dfplayer some time to start up, if still failed to start up, give error code and try again
  delay(700);
  if (!mp3Player.begin(mp3Serial)) {
    error(ERROR_DFPLAYER_INIT);
  }
  delay(200);

  mp3Player.volume(30);  //Set volume value. From 0 to 30


  // find the file count -> if fail, give error code, restart and try again
  int totFileCount = -1;
  int tryCountTot = 0;
  while (totFileCount == -1 && tryCountTot < 10) {
   delay(200);
   totFileCount = mp3Player.readFileCounts();
   tryCountTot++;
  }
  if (totFileCount == -1) {
    error(ERROR_FILE_COUNT);
  }

  // find the service file count -> if fail, give error code, restart and try again
  int serviceFileCount = -1;
  int tryCountService = 0;
  while (serviceFileCount == -1 && tryCountService < 10) {
   delay(200);
   serviceFileCount = mp3Player.readFileCountsInFolder(1);
   tryCountService++;
  }
  if (serviceFileCount == -1) {
    error(ERROR_SERVICE_FILE_COUNT);
  }
  
  delay(200);

  // use only the files in the mp3 folder
  songCount = totFileCount - serviceFileCount;

//  mp3Player.playMp3Folder(3);

}

void loop() {
  
  phoneState = phone.readState();
  
  if (phoneState == NUMBER_DIALED && !isPlayingSong && !isWaitingForHook) {
    char dialedNumber = phone.getNumber() + '0';
    number += dialedNumber;
    timeOfLastInput = millis();
  }
  
  if (phoneState == ON_HOOK) {
    // reset everything
    isPlayingSong = false;
    isWaitingForHook = false;
    timeOfLastInput = 0;
    number = "";
    mp3Player.stop();    
  }
  
  if (phoneState == DIALING && !isPlayingSong && !isWaitingForHook) {
    // reset everything
    timeOfLastInput = millis();
    isPlayingSong = false;
    isWaitingForHook = false;
    mp3Player.stop();
  }

  if (phoneState == OFF_HOOK) {
    // reset everything to be sure to start clean
    isPlayingSong = false;
    isWaitingForHook = false;
    timeOfLastInput = 0;
    number = "";
    mp3Player.loop(DIAL_TONE);
  }

  if (timeOfLastInput && millis() - timeOfLastInput > LONG_TIMEOUT && !isPlayingSong && !isWaitingForHook) {
    timeOfLastInput = 0;
    numberCalled(number);
    number = "";
  }

  if (isPlayingSong && digitalRead(PIN_BUSY) == HIGH) {
    // song is done, play disconnected sound!
    isPlayingSong = false;
    isWaitingForHook = true;
    mp3Player.loop(DISCONNECTED_TONE);
  }
}

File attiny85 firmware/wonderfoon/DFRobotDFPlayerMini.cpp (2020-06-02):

/*!
 * @file DFRobotDFPlayerMini.cpp
 * @brief DFPlayer - An Arduino Mini MP3 Player From DFRobot
 * @n Header file for DFRobot's DFPlayer
 *
 * @copyright  [DFRobot]( http://www.dfrobot.com ), 2016
 * @copyright GNU Lesser General Public License
 *
 * @author [Angelo](Angelo.qiao@dfrobot.com)
 * @version  V1.0.3
 * @date  2016-12-07
 */

#include "DFRobotDFPlayerMini.h"

void DFRobotDFPlayerMini::setTimeOut(unsigned long timeOutDuration){
  _timeOutDuration = timeOutDuration;
}

void DFRobotDFPlayerMini::uint16ToArray(uint16_t value, uint8_t *array){
  *array = (uint8_t)(value>>8);
  *(array+1) = (uint8_t)(value);
}

uint16_t DFRobotDFPlayerMini::calculateCheckSum(uint8_t *buffer){
  uint16_t sum = 0;
  for (int i=Stack_Version; i<Stack_CheckSum; i++) {
    sum += buffer[i];
  }
  return -sum;
}

void DFRobotDFPlayerMini::sendStack(){
  if (_sending[Stack_ACK]) {  //if the ack mode is on wait until the last transmition
    while (_isSending) {
      delay(0);
      available();
    }
  }

#ifdef _DEBUG
  Serial.println();
  Serial.print(F("sending:"));
  for (int i=0; i<DFPLAYER_SEND_LENGTH; i++) {
    Serial.print(_sending[i],HEX);
    Serial.print(F(" "));
  }
  Serial.println();
#endif
  _serial->write(_sending, DFPLAYER_SEND_LENGTH);
  _timeOutTimer = millis();
  _isSending = _sending[Stack_ACK];
  
  if (!_sending[Stack_ACK]) { //if the ack mode is off wait 10 ms after one transmition.
    delay(10);
  }
}

void DFRobotDFPlayerMini::sendStack(uint8_t command){
  sendStack(command, 0);
}

void DFRobotDFPlayerMini::sendStack(uint8_t command, uint16_t argument){
  _sending[Stack_Command] = command;
  uint16ToArray(argument, _sending+Stack_Parameter);
  uint16ToArray(calculateCheckSum(_sending), _sending+Stack_CheckSum);
  sendStack();
}

void DFRobotDFPlayerMini::sendStack(uint8_t command, uint8_t argumentHigh, uint8_t argumentLow){
  uint16_t buffer = argumentHigh;
  buffer <<= 8;
  sendStack(command, buffer | argumentLow);
}

void DFRobotDFPlayerMini::enableACK(){
  _sending[Stack_ACK] = 0x01;
}

void DFRobotDFPlayerMini::disableACK(){
  _sending[Stack_ACK] = 0x00;
}

bool DFRobotDFPlayerMini::waitAvailable(unsigned long duration){
  unsigned long timer = millis();
  if (!duration) {
    duration = _timeOutDuration;
  }
  while (!available()){
    if (millis() - timer > duration) {
      return false;
    }
    delay(0);
  }
  return true;
}

bool DFRobotDFPlayerMini::begin(Stream &stream, bool isACK, bool doReset){
  _serial = &stream;
  
  if (isACK) {
    enableACK();
  }
  else{
    disableACK();
  }
  
  if (doReset) {
    reset();
    waitAvailable(2000);
    delay(200);
  }
  else {
    // assume same state as with reset(): online
    _handleType = DFPlayerCardOnline;
  }

  return (readType() == DFPlayerCardOnline) || (readType() == DFPlayerUSBOnline) || !isACK;
}

uint8_t DFRobotDFPlayerMini::readType(){
  _isAvailable = false;
  return _handleType;
}

uint16_t DFRobotDFPlayerMini::read(){
  _isAvailable = false;
  return _handleParameter;
}

bool DFRobotDFPlayerMini::handleMessage(uint8_t type, uint16_t parameter){
  _receivedIndex = 0;
  _handleType = type;
  _handleParameter = parameter;
  _isAvailable = true;
  return _isAvailable;
}

bool DFRobotDFPlayerMini::handleError(uint8_t type, uint16_t parameter){
  handleMessage(type, parameter);
  _isSending = false;
  return false;
}

uint8_t DFRobotDFPlayerMini::readCommand(){
  _isAvailable = false;
  return _handleCommand;
}

void DFRobotDFPlayerMini::parseStack(){
  uint8_t handleCommand = *(_received + Stack_Command);
  if (handleCommand == 0x41) { //handle the 0x41 ack feedback as a spcecial case, in case the pollusion of _handleCommand, _handleParameter, and _handleType.
    _isSending = false;
    return;
  }
  
  _handleCommand = handleCommand;
  _handleParameter =  arrayToUint16(_received + Stack_Parameter);

  switch (_handleCommand) {
    case 0x3D:
      handleMessage(DFPlayerPlayFinished, _handleParameter);
      break;
    case 0x3F:
      if (_handleParameter & 0x01) {
        handleMessage(DFPlayerUSBOnline, _handleParameter);
      }
      else if (_handleParameter & 0x02) {
        handleMessage(DFPlayerCardOnline, _handleParameter);
      }
      else if (_handleParameter & 0x03) {
        handleMessage(DFPlayerCardUSBOnline, _handleParameter);
      }
      break;
    case 0x3A:
      if (_handleParameter & 0x01) {
        handleMessage(DFPlayerUSBInserted, _handleParameter);
      }
      else if (_handleParameter & 0x02) {
        handleMessage(DFPlayerCardInserted, _handleParameter);
      }
      break;
    case 0x3B:
      if (_handleParameter & 0x01) {
        handleMessage(DFPlayerUSBRemoved, _handleParameter);
      }
      else if (_handleParameter & 0x02) {
        handleMessage(DFPlayerCardRemoved, _handleParameter);
      }
      break;
    case 0x40:
      handleMessage(DFPlayerError, _handleParameter);
      break;
    case 0x3C:
    case 0x3E:
    case 0x42:
    case 0x43:
    case 0x44:
    case 0x45:
    case 0x46:
    case 0x47:
    case 0x48:
    case 0x49:
    case 0x4B:
    case 0x4C:
    case 0x4D:
    case 0x4E:
    case 0x4F:
      handleMessage(DFPlayerFeedBack, _handleParameter);
      break;
    default:
      handleError(WrongStack);
      break;
  }
}

uint16_t DFRobotDFPlayerMini::arrayToUint16(uint8_t *array){
  uint16_t value = *array;
  value <<=8;
  value += *(array+1);
  return value;
}

bool DFRobotDFPlayerMini::validateStack(){
  return calculateCheckSum(_received) == arrayToUint16(_received+Stack_CheckSum);
}
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

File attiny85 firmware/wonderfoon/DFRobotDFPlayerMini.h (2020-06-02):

/*!
 * @file DFRobotDFPlayerMini.h
 * @brief DFPlayer - An Arduino Mini MP3 Player From DFRobot
 * @n Header file for DFRobot's DFPlayer
 *
 * @copyright  [DFRobot]( http://www.dfrobot.com ), 2016
 * @copyright GNU Lesser General Public License
 *
 * @author [Angelo](Angelo.qiao@dfrobot.com)
 * @version  V1.0.3
 * @date  2016-12-07
 */

#include "Arduino.h"

#ifndef DFRobotDFPlayerMini_cpp
    #define DFRobotDFPlayerMini_cpp


#define DFPLAYER_EQ_NORMAL 0
#define DFPLAYER_EQ_POP 1
#define DFPLAYER_EQ_ROCK 2
#define DFPLAYER_EQ_JAZZ 3
#define DFPLAYER_EQ_CLASSIC 4
#define DFPLAYER_EQ_BASS 5

#define DFPLAYER_DEVICE_U_DISK 1
#define DFPLAYER_DEVICE_SD 2
#define DFPLAYER_DEVICE_AUX 3
#define DFPLAYER_DEVICE_SLEEP 4
#define DFPLAYER_DEVICE_FLASH 5

#define DFPLAYER_RECEIVED_LENGTH 10
#define DFPLAYER_SEND_LENGTH 10

//#define _DEBUG

#define TimeOut 0
#define WrongStack 1
#define DFPlayerCardInserted 2
#define DFPlayerCardRemoved 3
#define DFPlayerCardOnline 4
#define DFPlayerPlayFinished 5
#define DFPlayerError 6
#define DFPlayerUSBInserted 7
#define DFPlayerUSBRemoved 8
#define DFPlayerUSBOnline 9
#define DFPlayerCardUSBOnline 10
#define DFPlayerFeedBack 11

#define Busy 1
#define Sleeping 2
#define SerialWrongStack 3
#define CheckSumNotMatch 4
#define FileIndexOut 5
#define FileMismatch 6
#define Advertise 7

#define Stack_Header 0
#define Stack_Version 1
#define Stack_Length 2
#define Stack_Command 3
#define Stack_ACK 4
#define Stack_Parameter 5
#define Stack_CheckSum 7
#define Stack_End 9

class DFRobotDFPlayerMini {
  Stream* _serial;
  
  unsigned long _timeOutTimer;
  unsigned long _timeOutDuration = 500;
  
  uint8_t _received[DFPLAYER_RECEIVED_LENGTH];
  uint8_t _sending[DFPLAYER_SEND_LENGTH] = {0x7E, 0xFF, 06, 00, 01, 00, 00, 00, 00, 0xEF};
  
  uint8_t _receivedIndex=0;

  void sendStack();
  void sendStack(uint8_t command);
  void sendStack(uint8_t command, uint16_t argument);
  void sendStack(uint8_t command, uint8_t argumentHigh, uint8_t argumentLow);

  void enableACK();
  void disableACK();
  
  void uint16ToArray(uint16_t value,uint8_t *array);
  
  uint16_t arrayToUint16(uint8_t *array);
  
  uint16_t calculateCheckSum(uint8_t *buffer);
  


  void parseStack();
  bool validateStack();
  
  uint8_t device = DFPLAYER_DEVICE_SD;
  
  public:
  
  uint8_t _handleType;
  uint8_t _handleCommand;
  uint16_t _handleParameter;
  bool _isAvailable = false;
  bool _isSending = false;
  
  bool handleMessage(uint8_t type, uint16_t parameter = 0);
  bool handleError(uint8_t type, uint16_t parameter = 0);

  uint8_t readCommand();
  
  bool begin(Stream& stream, bool isACK = true, bool doReset = true);
  
  bool waitAvailable(unsigned long duration = 0);
  
  bool available();
  
  uint8_t readType();
  
  uint16_t read();
  
  void setTimeOut(unsigned long timeOutDuration);
  
  void next();
  
  void previous();
  
  void play(int fileNumber=1);
  
  void volumeUp();
  
  void volumeDown();
  
  void volume(uint8_t volume);
  
  void EQ(uint8_t eq);
  
  void loop(int fileNumber);
  
  void outputDevice(uint8_t device);
  
  void sleep();
  
  void reset();
  
  void start();
  
  void pause();
  
  void playFolder(uint8_t folderNumber, uint8_t fileNumber);
  
  void outputSetting(bool enable, uint8_t gain);
  
  void enableLoopAll();
  
  void disableLoopAll();
  
  void playMp3Folder(int fileNumber);
  
  void advertise(int fileNumber);
  
  void playLargeFolder(uint8_t folderNumber, uint16_t fileNumber);
  
  void stopAdvertise();
  
  void stop();
  
  void loopFolder(int folderNumber);
  
  void randomAll();
  
  void enableLoop();
  
  void disableLoop();
  
  void enableDAC();
  
  void disableDAC();
  
  int readState();
  
  int readVolume();
  
  int readEQ();
  
  int readFileCounts(uint8_t device);
  
  int readCurrentFileNumber(uint8_t device);
  
  int readFileCountsInFolder(int folderNumber);
  
  int readFileCounts();

  int readFolderCounts();
  
  int readCurrentFileNumber();
  
};

#endif

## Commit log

2020-06-04 add new pcbs message
2020-06-18 pcb and firmware v3
    [printplaat-B_Cu.gbr, printplaat-B_Mask.gbr, printplaat-B_SilkS.gbr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]
2020-06-18 updated gerber files
    [printplaat-B_Cu.gbr, printplaat-B_Mask.gbr, printplaat-B_SilkS.gbr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]
